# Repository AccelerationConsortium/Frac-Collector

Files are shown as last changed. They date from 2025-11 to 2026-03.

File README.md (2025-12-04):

# Low-Cost, Python-Controlled, Solvent-Resistant Fraction Collector for Automated Flow Synthesis 

## Overview
This repository contains all design files, firmware, and documentation for a **low-cost, modular, and solvent-resistant fraction collector** designed for use in **automated flow chemistry applications**.

Developed to address the limitations of commercial and open-source fraction collectors, especially in handling **organic solvents**. This system integrates seamlessly with flow reactors for unattended, reproducible fraction collection. Features include:
- Compatibility with common organic solvents (e.g. Tetrahydrofuran, Tolyene, Acetone, Chloroform, Ethyl Acetate, Isopropanol)
- Programmable 3-axis benchtop CNC platform for flexible configurations
- Drop-counting and real-time volume feedback for accurate collection
- Python-based control interface for full automation
- Compact design suitable for chemistry fume hoods
- Mininimal number of components and easy to assemble
- Total build cost: approximately **$1,000 USD**

---

## Assembly Guide
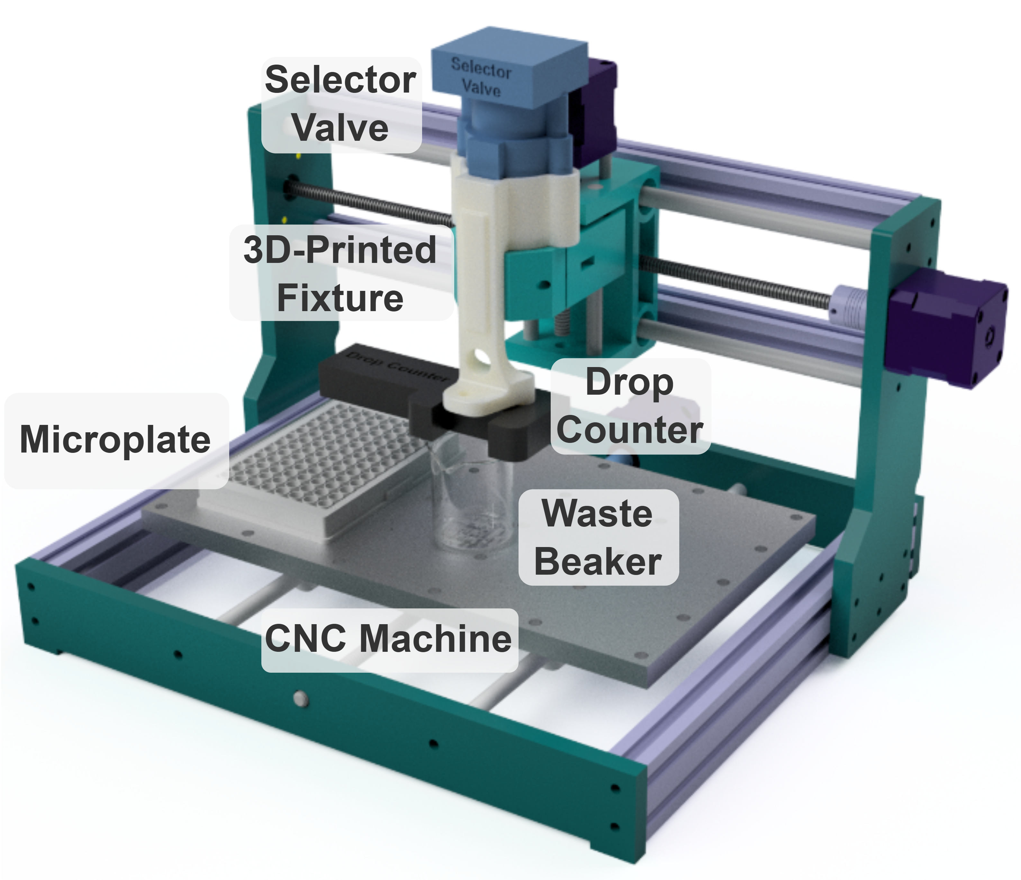
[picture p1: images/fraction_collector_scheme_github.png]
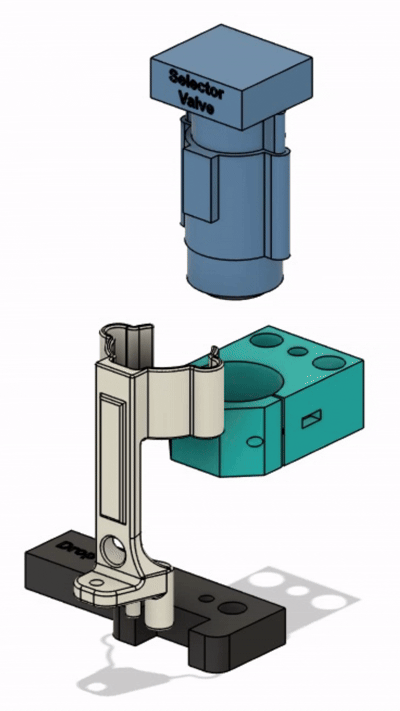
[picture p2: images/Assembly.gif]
 &nbsp;&nbsp;&nbsp; 
### Bill of Materials (BoM)
The BoM to construct the fraction collector is shown below. 

| **Item** | **Manufacturer** | **Part No.** | **Qty** | **Specifications** | **Unit Cost (USD)** | **Notes** |
| --- | --- | --- | ---: | --- | ---: | --- |
| CNC Router | Genmitsu | [3018-PROVer V2](https://www.sainsmart.com/products/genmitsu-3018-prover-v2-upgraded-semi-assembled-cnc-router-kit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) | 1 | 425 × 352 × 300 mm | $228.65 | Main platform |
| Selector Valve | Runze Fluid | [QHF-SV04M-B-X-U-T10-K1.2-C](https://www.runzefluid.com/products/multi-channel-selector-valves.html) | 1 | 10 Port or 6 Port | $414.00 | Switching between waste and collection |
| Drop Counter | Vernier® | [GDX-DC](https://www.vernier.com/product/go-direct-drop-counter/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) | 1 | Go Direct® | $206.00 | For drop counting |
| Fixture | N/A | N/A | 1 | [Custom 3D-Printed](3D-printed_fixture.step) | $2.00 (est.) | For integrating modules |
| Tubing | IDEX | [1502](https://www.idex-hs.com/store/product-detail/pfa_tubing_natural_1_16_od_x_030_id_x_5ft/1502) | ≥5 ft | 1/16″ OD × 0.030″ ID, PFA | $28.45 | Tubing |
| Flangeless Nut | IDEX | [P-245](https://www.idex-hs.com/store/product-detail/flangeless_nut_pfa_1_4_28_flat_bottom_for_1_16_od_natural/p-245) | ≥5 | 1/4-28, PFA | $3.36 each | Tubing connector |
| Ferrule | IDEX | [P-200N](https://www.idex-hs.com/store/product-detail/flangeless_ferrule_tefzel_etfe_1_4_28_flat_bottom_for_1_16_od_natural/p-200n) | ≥5 | 1/4-28 for 1/16″ OD, ETFE | $1.79 each | Tubing connector |

### Mechanical Assembly
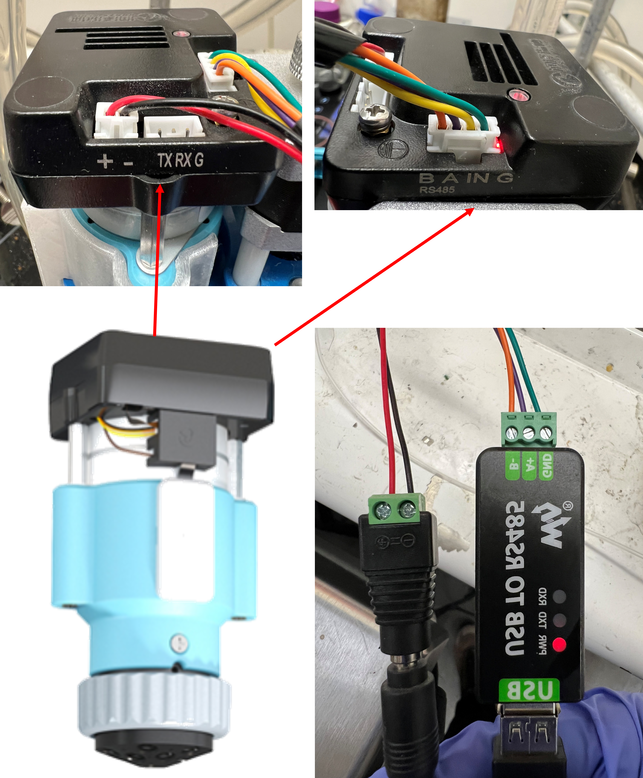
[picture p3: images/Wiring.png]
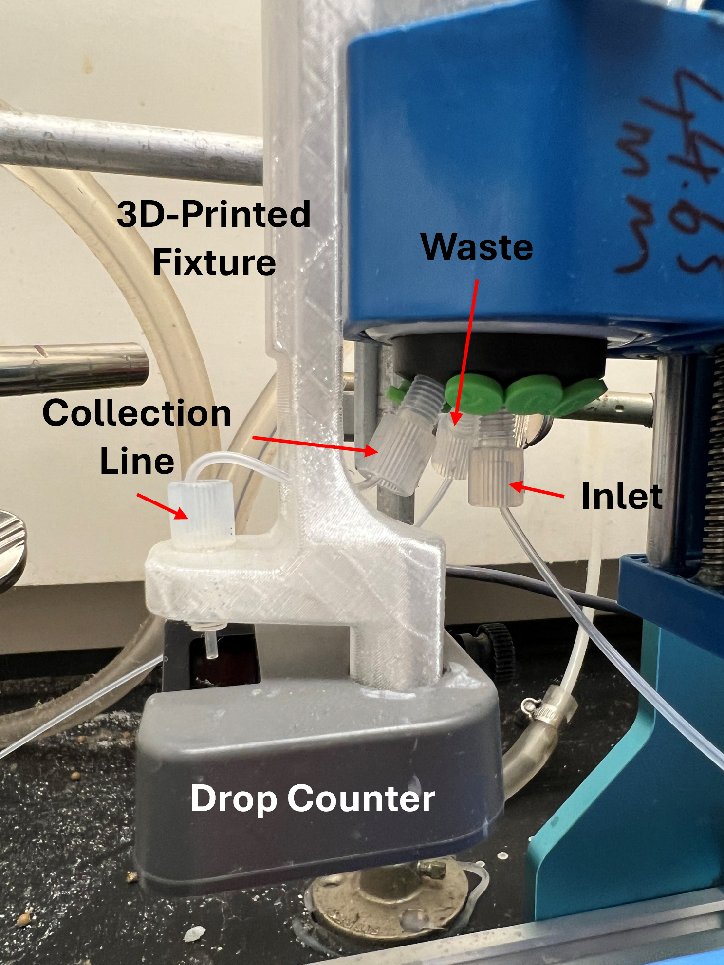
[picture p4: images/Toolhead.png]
 &nbsp;&nbsp;&nbsp;    
1. **CNC Platform Setup (1-2 hours)**
   - Assemble CNC frame per manufacturer instructions.
   - Mount custom vial tray or holder onto the platform.

2. **Selector Valve Integration (30 min)**
   - Wire the connectors following the above wiring guideline.
   - Secure the selector valve on the 3D-printed fixture and the CNC tool head.
   - Route the inlet, waste, and collection lines through chemically resistant tubing and nuts.

3. **Drop Counter Installation (30 min)**
   - Secure the drop counter on the 3D-printed fixture.
   - Calibrate sensor and tubing height to detect single droplets accurately.

### Software & Control
- The fraction collector is fully controlled via a Python interface using the code in the repository.

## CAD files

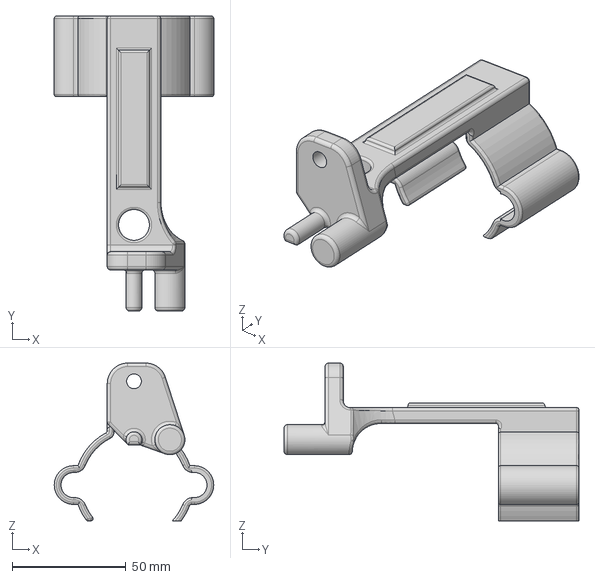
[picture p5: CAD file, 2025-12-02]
3D-printed_fixture.step
70.0 x 129.4 x 69.2 mm

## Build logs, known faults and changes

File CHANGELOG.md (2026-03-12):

# Changelog

## [Unreleased] - 2026-03-12

### Changed
- `collect_fraction`: `threshold` parameter renamed to `threshold_ml` (volume in mL). `rinse_drop` parameter renamed to `rinse_ml` (default `0.16` mL = 20 drops). Both are converted internally to drop counts using `math.floor(ml / 0.008)` (1 drop = 8 µL).
- `workflow_flowreactor.ipynb`: updated `collect_fraction` call arguments from drop counts (140, 70) to mL values (1.12, 0.56).
- `vapourtec_api/API/20260311_SL_synthesis_collection_workflow.ipynb`: renamed `DROP_THRESHOLD` to `DROP_THRESHOLD_ML = 1.6` and updated the `collect_fraction` keyword argument to `threshold_ml`.

### Added
- `FractionCollector.collect_reaction`: new method that collects an entire reaction across consecutive vials. Sets the fraction collector valve to collect at the start of the collection window and to waste at the end. When a vial reaches `threshold_ml`, the CNC moves to the next vial automatically. Collection continues until `collection_duration_s` elapses. Returns a dict with `reaction_name`, `vials_used` (list of indices), `num_vials`, `start_time`, and `end_time`.
- Module constant `DROP_VOLUME_ML = 0.008` in `fraction_collector.py`.

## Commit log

2025-11-27 Revise README with project details and assembly guide
    Updated README to include detailed project overview, assembly guide, and bill of materials for the fraction collector.
2025-11-27 Upload Pictures and Assembly Guide
2025-11-27 Fix formatting in Assembly Guide section of README
2025-12-02 Create 3D-printed fixture.step
    [3D-printed fixture.step]
2025-12-02 updated 3D-printed_fixture
    [3D-printed_fixture.step]
2025-12-02 Add link to 3D-printed fixture in README
    Updated the fixture description to include a link to the 3D model.
2025-12-04 Fix image formatting in Assembly Guide
    Adjusted image display in Assembly Guide section.
2026-04-15 updated data
    [Fractions_August19_2025.csv, NMR HCW_8_1.csv, NMR HCW_8_2.csv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]
